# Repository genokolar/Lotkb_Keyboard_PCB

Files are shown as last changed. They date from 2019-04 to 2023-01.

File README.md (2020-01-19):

# Lotkb_Keyboard_PCB
A bluetooth keyboard powered by Lotkb, PCB by Kicad, Schematic fork of https://github.com/Lotlab/BLE60-keyboard  
一个采用Kicad设计制作的Lotkb驱动的蓝牙键盘PCB，原理图参考Lotlab的蓝牙键盘进行更改优化。

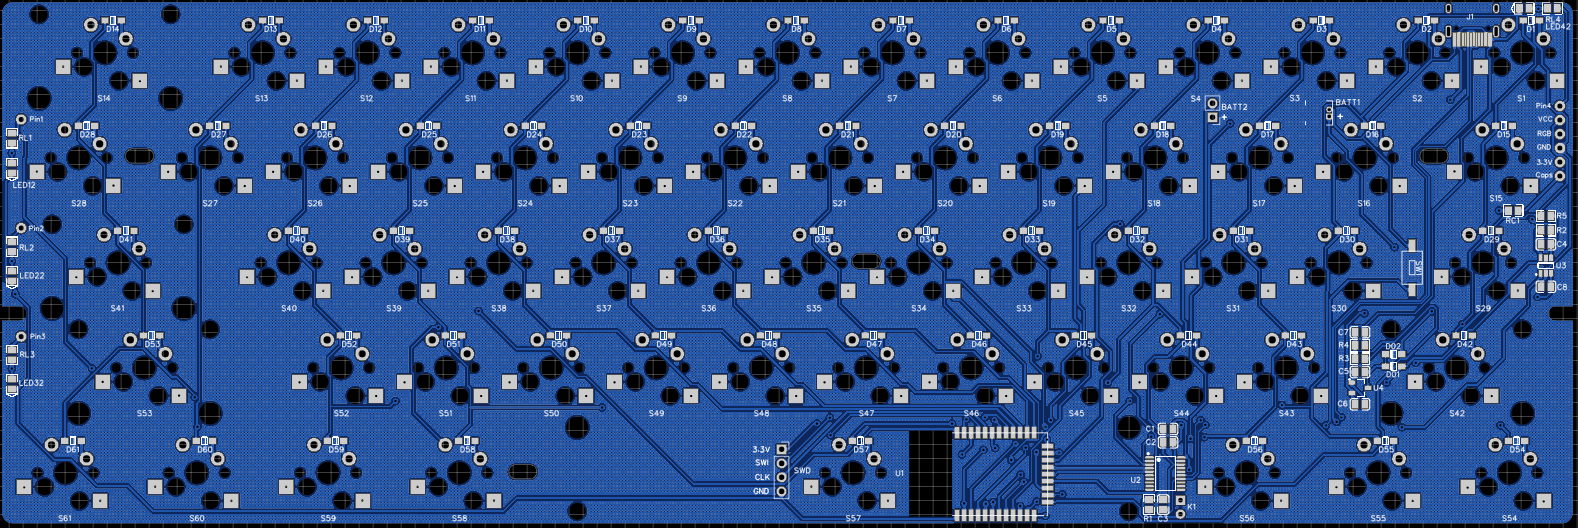
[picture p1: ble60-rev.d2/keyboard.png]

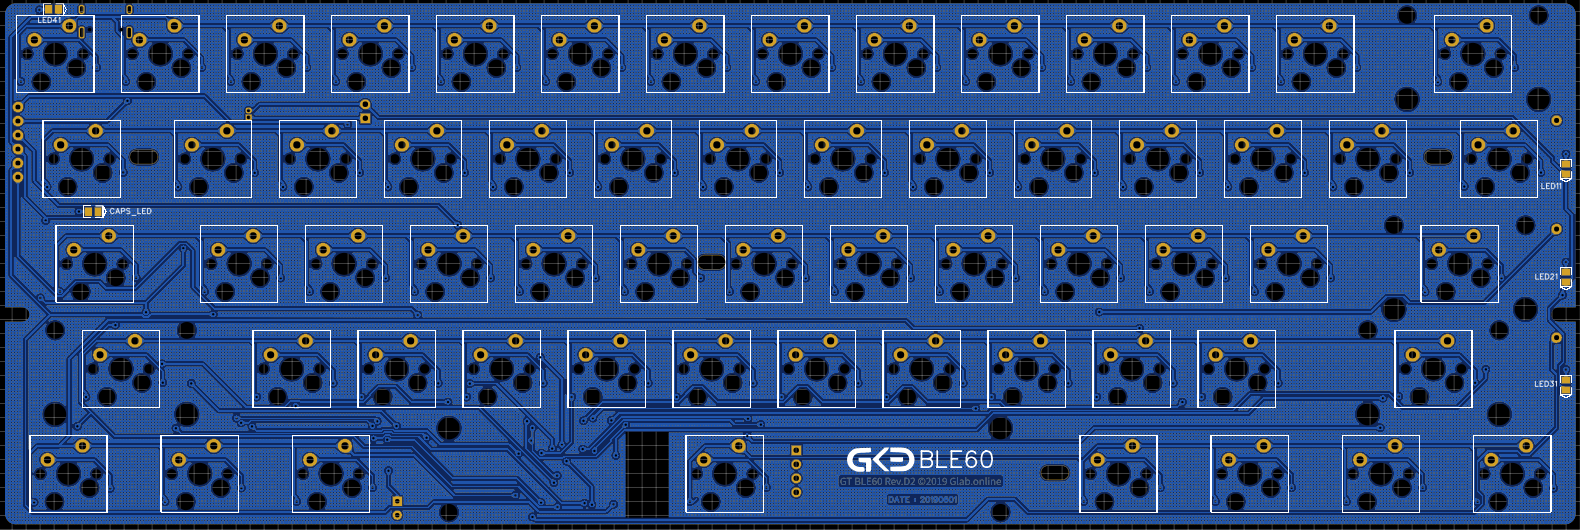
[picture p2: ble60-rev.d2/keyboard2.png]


**生产用Gerber文件可直接用于生产，BOM文件与贴装坐标文件也可直接用于贴装**

using nRF52(or nRF51)  and CH554(or CH552).  
使用 nRF52(或者nRF51) 与 CH554（或者CH552）芯片

Firmware Source Code/固件源码: 
- [nrf51822-keyboard](https://github.com/genokolar/nrf51822-keyboard/tree/GT-BLE60)
- [nrf52-keyboard](https://github.com/genokolar/nrf52-keyboard)

More description/详细信息在此查看：[https://glab.online/](https://glab.online/)

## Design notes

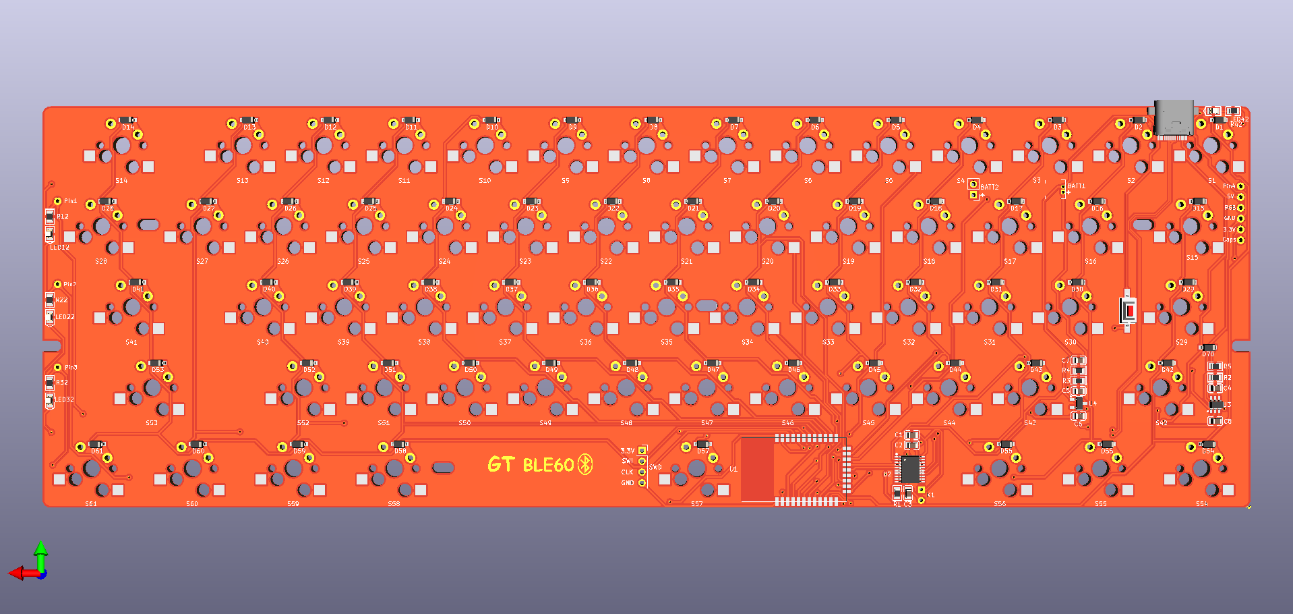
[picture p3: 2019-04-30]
ble60-rev.d/keyboard2.png

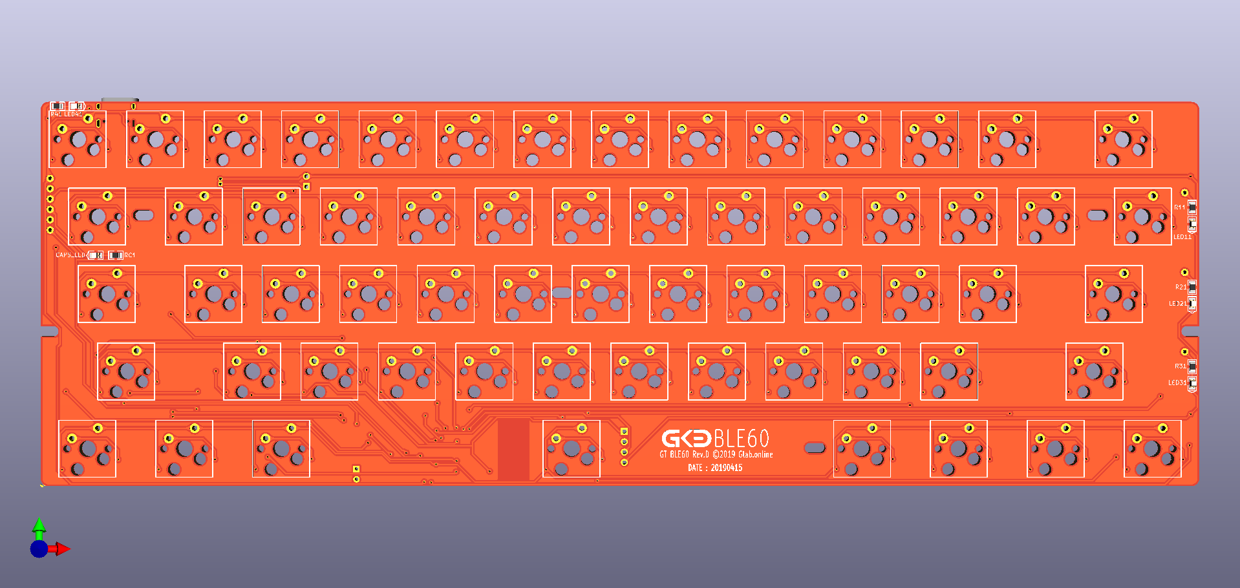
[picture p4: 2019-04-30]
ble60-rev.d/keyboard.png

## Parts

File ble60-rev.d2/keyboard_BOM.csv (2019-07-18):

Comment | Description | Designator | Footprint | LibRef | Pins | Quantity | PartNumber | url
0.1uF | 贴片电容 | C1,C2, | JLC_0805C | libref | 2 | 2
NC/47pF | 贴片电容 | C3, | JLC_0805C | libref | 2 | 1
1uF | 贴片电容 | C4,C5,C6, | JLC_0805C | libref | 2 | 3
10nF | 贴片电容 | C7, | JLC_0805C | libref | 2 | 1
10uF | 贴片电容 | C8, | JLC_0805C | libref | 2 | 1
B5819W SL | 肖特基二极管 | D01,D02, | JLC_SOD-123 | libref | 2 | 2 |  | http://www.vishay.com/docs/88525/1n5817.pdf
1N4148W | 开关二极管 | D1,D2,D3,D4,D5,D6,D7,D8,D9,D10,D11,D12,D13,D14,D15,D16,D17,D18,D19,D20,D21,D22,D23,D24,D25,D26,D27,D28,D29,D30,D31,D32,D33,D34,D35,D36,D37,D38,D39,D40,D41,D42,D43,D44,D45,D46,D47,D48,D49,D50,D51,D52,D53,D54,D55,D56,D57,D58,D59,D60,D61, | JLC_SOD-123 | libref | 2 | 61 |  | https://atta.szlcsc.com/upload/public/pdf/source/20161024/1477288446905.pdf
White LED | 0805 LED | CAPS_LED1, | JLC_0805_LED | libref | 2 | 1
Red LED | 0805 LED | LED11, | JLC_0805_LED | libref | 2 | 1
Red LED | 0805 LED | LED12, | JLC_0805_LED | libref | 2 | 1
Blue LED | 0805 LED | LED21, | JLC_0805_LED | libref | 2 | 1
Blue LED | 0805 LED | LED22, | JLC_0805_LED | libref | 2 | 1
Green LED | 0805 LED | LED31, | JLC_0805_LED | libref | 2 | 1
Green LED | 0805 LED | LED32, | JLC_0805_LED | libref | 2 | 1
Orange LED | 0805 LED | LED41, | JLC_0805_LED | libref | 2 | 1
Orange LED | 0805 LED | LED42, | JLC_0805_LED | libref | 2 | 1
10K | 贴片电阻 | R1, | JLC_0805R | libref | 2 | 1
4.7K | 贴片电阻 | R2, | JLC_0805R | libref | 2 | 1
10M | 贴片电阻 | R3, | JLC_0805R | libref | 2 | 1
2.2M | 贴片电阻 | R4, | JLC_0805R | libref | 2 | 1
1R | 贴片电阻 | R5, | JLC_0805R | libref | 2 | 1
330R | 贴片电阻 | RL3,RL2,RL1,RC1,RL4, | JLC_0805R | libref | 2 | 5
TP4057 | 锂电池充电芯片 | U3, | JLC_SOT-23-6 | libref | 6 | 1 |  | https://atta.szlcsc.com/upload/public/pdf/source/20140228/1457706997013.pdf
XC6206P332MR | 低压差线性稳压 | U4, | JLC_SOT-23-3L | libref | 3 | 1 |  | https://atta.szlcsc.com/upload/public/pdf/source/20130801/1457706628791.pdf
不贴装元件
RF-BM-ND04 | 蓝牙主控板 | U1, | RF-BM-ND01 | LibRef | 33 | 1 |  | https://item.taobao.com/item.htm?spm=a1z09.2.0.0.24672e8d1aBt7Y&id=563254559292&_u=imp3j1b519
CH552T | USB芯片 | U2, | JLC_TSSOP-20 | LibRef | 20 | 1 |  | https://item.taobao.com/item.htm?spm=a1z10.3-c-s.w4002-21223910208.9.55dc6a4bV8yMGt&id=574979089030
Bootloader Button | Bootloader按钮 | SW1, | Switch | LibRef | 2 | 1 |  | https://item.taobao.com/item.htm?spm=a1z09.2.0.0.403d2e8dNmbyeE&id=556985020016&_u=4mp3j15e56
MX1A | MX轴体or凯华轴座 | S6,S28,S2,S4,S5,S7,S8,S9,S10,S11,S12,S13,S14,S15,S16,S17,S18,S19,S20,S21,S22,S23,S24,S25,S26,S27,S29,S30,S31,S32,S33,S34,S35,S36,S37,S38,S39,S40,S41,S42,S43,S44,S45,S46,S47,S48,S49,S50,S51,S52,S53,S54,S55,S56,S57,S58,S59,S60,S61,S1,S3, | Kailh_socket_optional | LibRef | 9 | 61
1.25mm | 1.25mm2P弯针电池接口母座 | BATT1, | PinHeader_2x1.25mm | LibRef | 2 | 1 |  | https://item.taobao.com/item.htm?spm=a1z0d.6639537.1997196601.58.47cf7484bbDVc8&id=528795201308
2.54mm | 2.54mm2P电池接口 | BATT2, | PinHeader_1x02_P2.54mm_Vertical | LibRef | 2 | 1
USB_TYPE_C | 贴片USB-3.1插座 16P | J1, | type-c | LibRef | 18 | 1 |  | https://item.taobao.com/item.htm?spm=a1z0d.6639537.1997196601.76.47cf7484bbDVc8&id=573090887123

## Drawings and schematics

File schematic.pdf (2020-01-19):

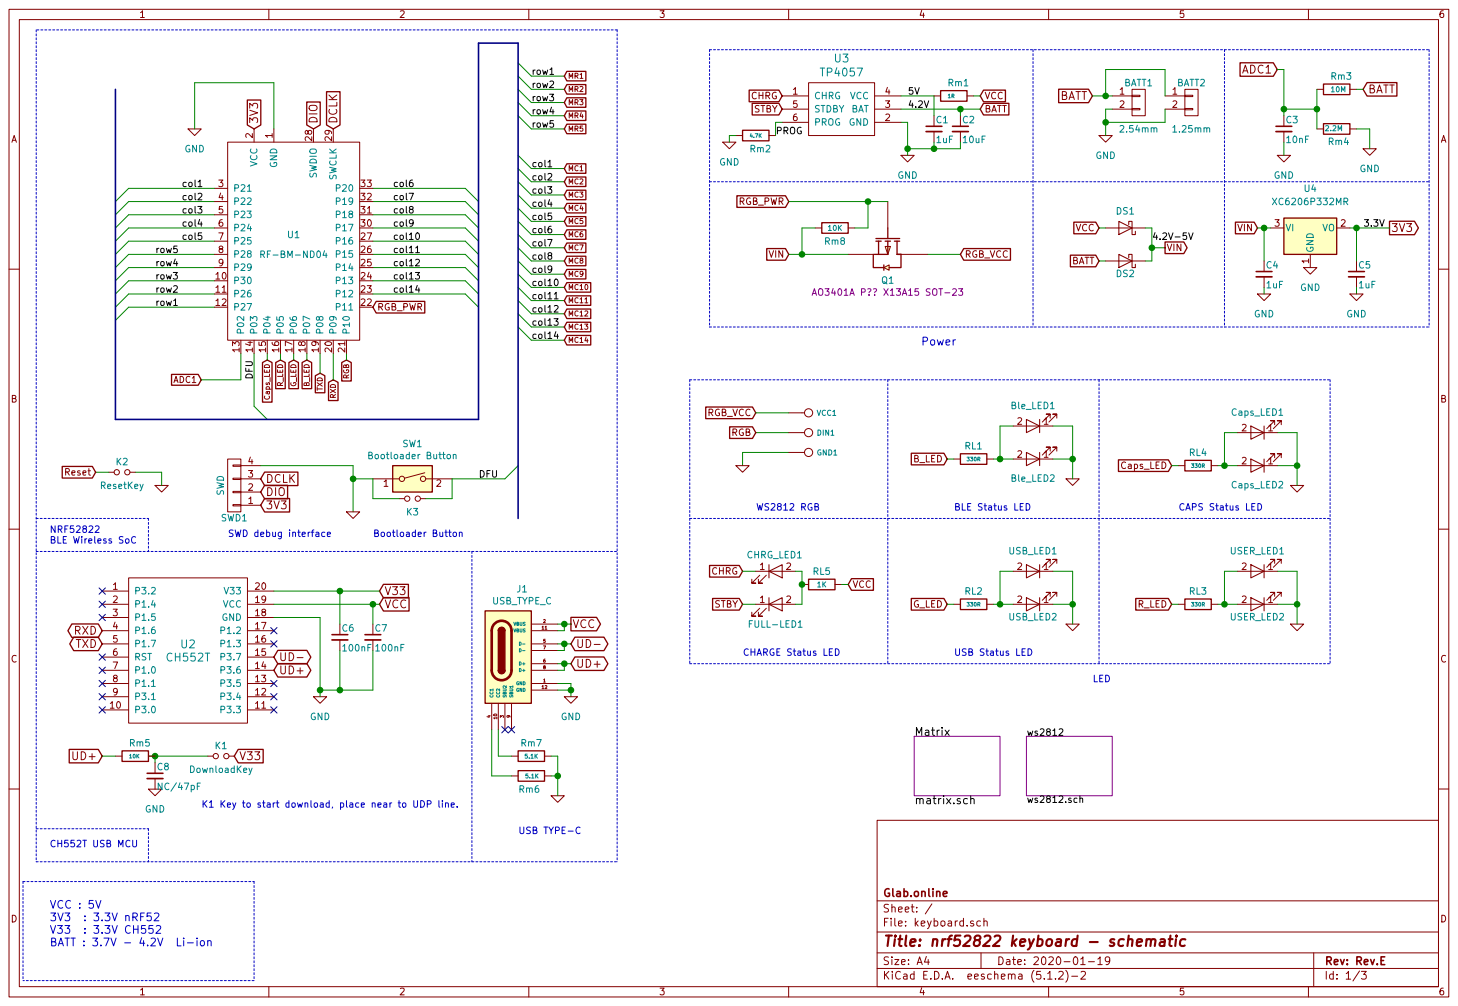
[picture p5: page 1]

2 P09 20 P10 21 P11 22 P12 23 P13 24 P14 25 P15 26 P16 27 SWDIO 28 SWCLK 29 P21 3 P17 30 P18 31 P19 32 P20 33 P22 4 P23 5 P24 6 P25 7 P28 8 P29 9 U1 RF-BM-ND04 CHRG

GND UD+ UD- RXD
TXD

File: keyboard.sch Sheet: / Glab.online

Id: 1/3 Title: nrf52822 keyboard - schematic

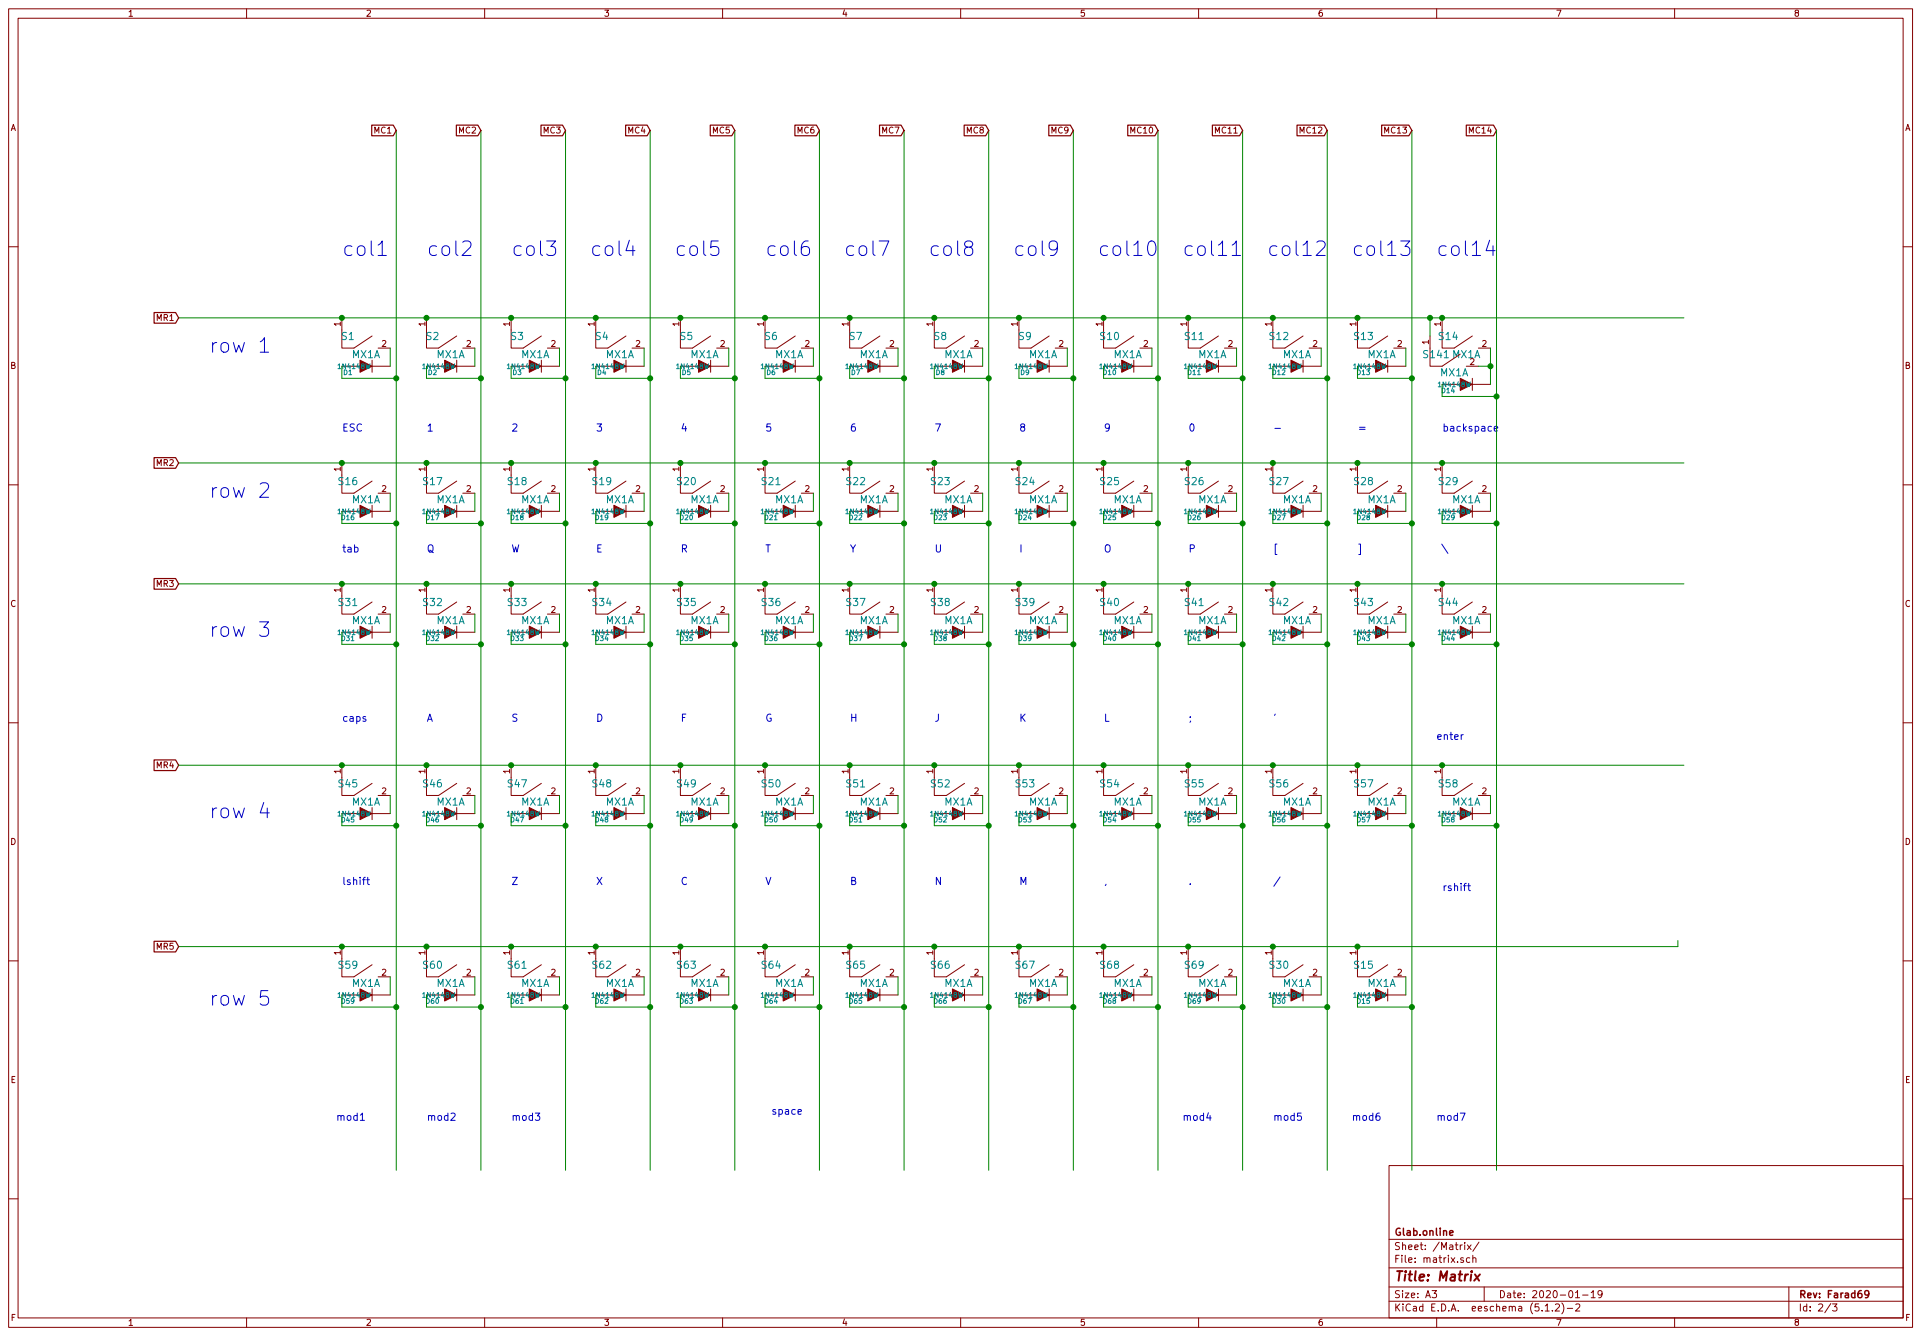
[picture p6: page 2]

File: matrix.sch Sheet: /Matrix/ Glab.online

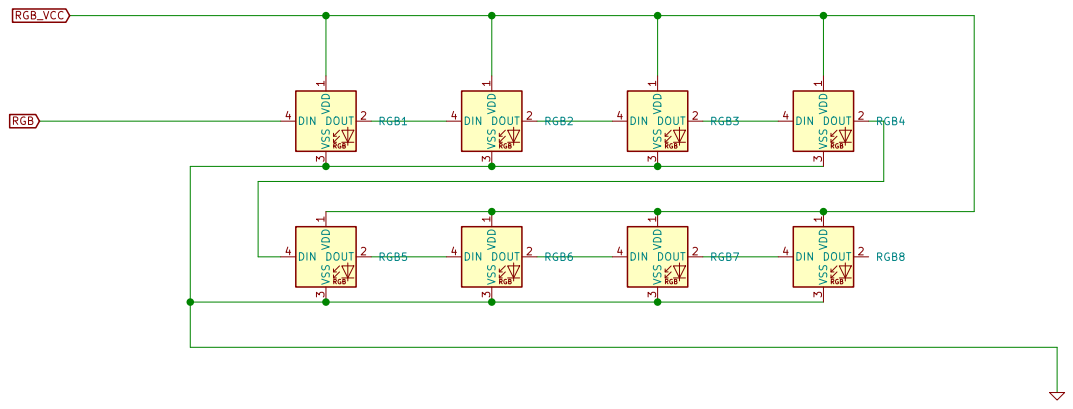
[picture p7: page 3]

File: ws2812.sch Sheet: /ws2812/ Glab.online

Id: 3/3 Title: nrf52822 keyboard - schematic

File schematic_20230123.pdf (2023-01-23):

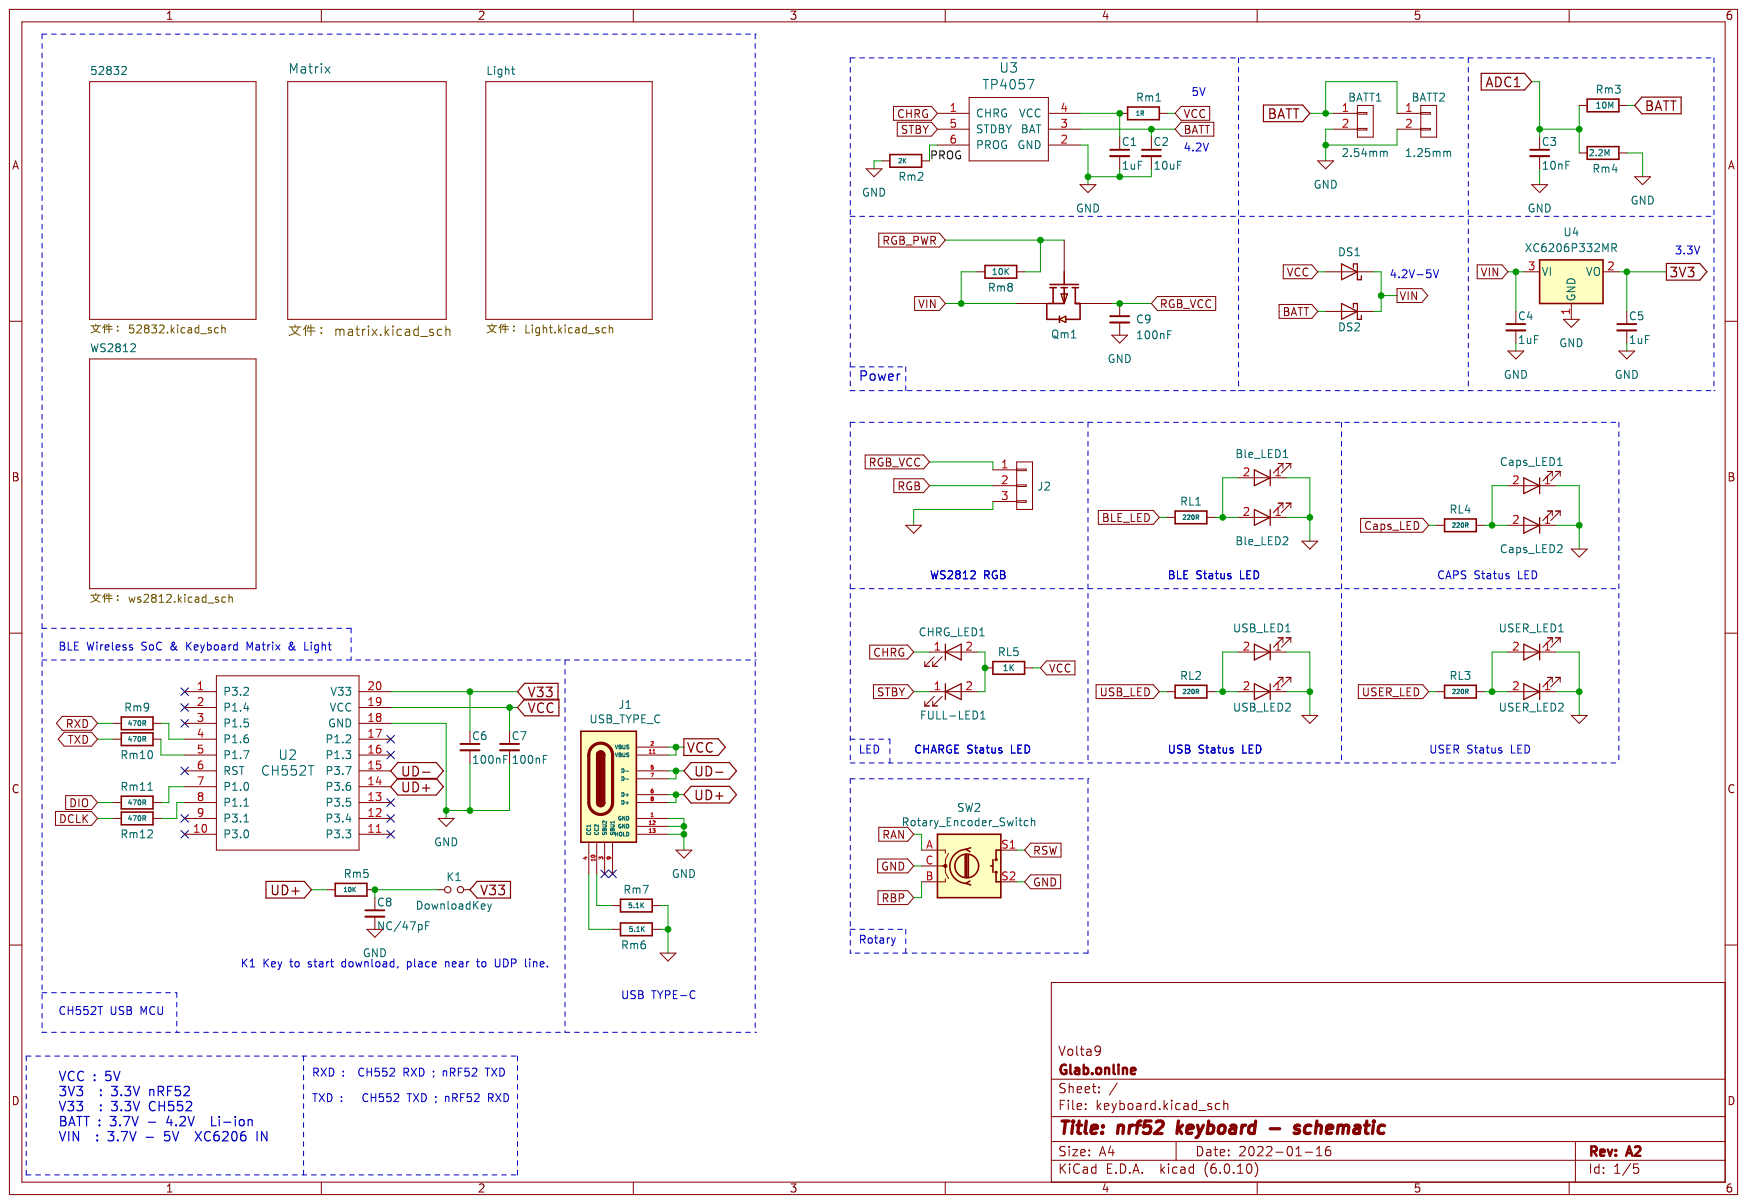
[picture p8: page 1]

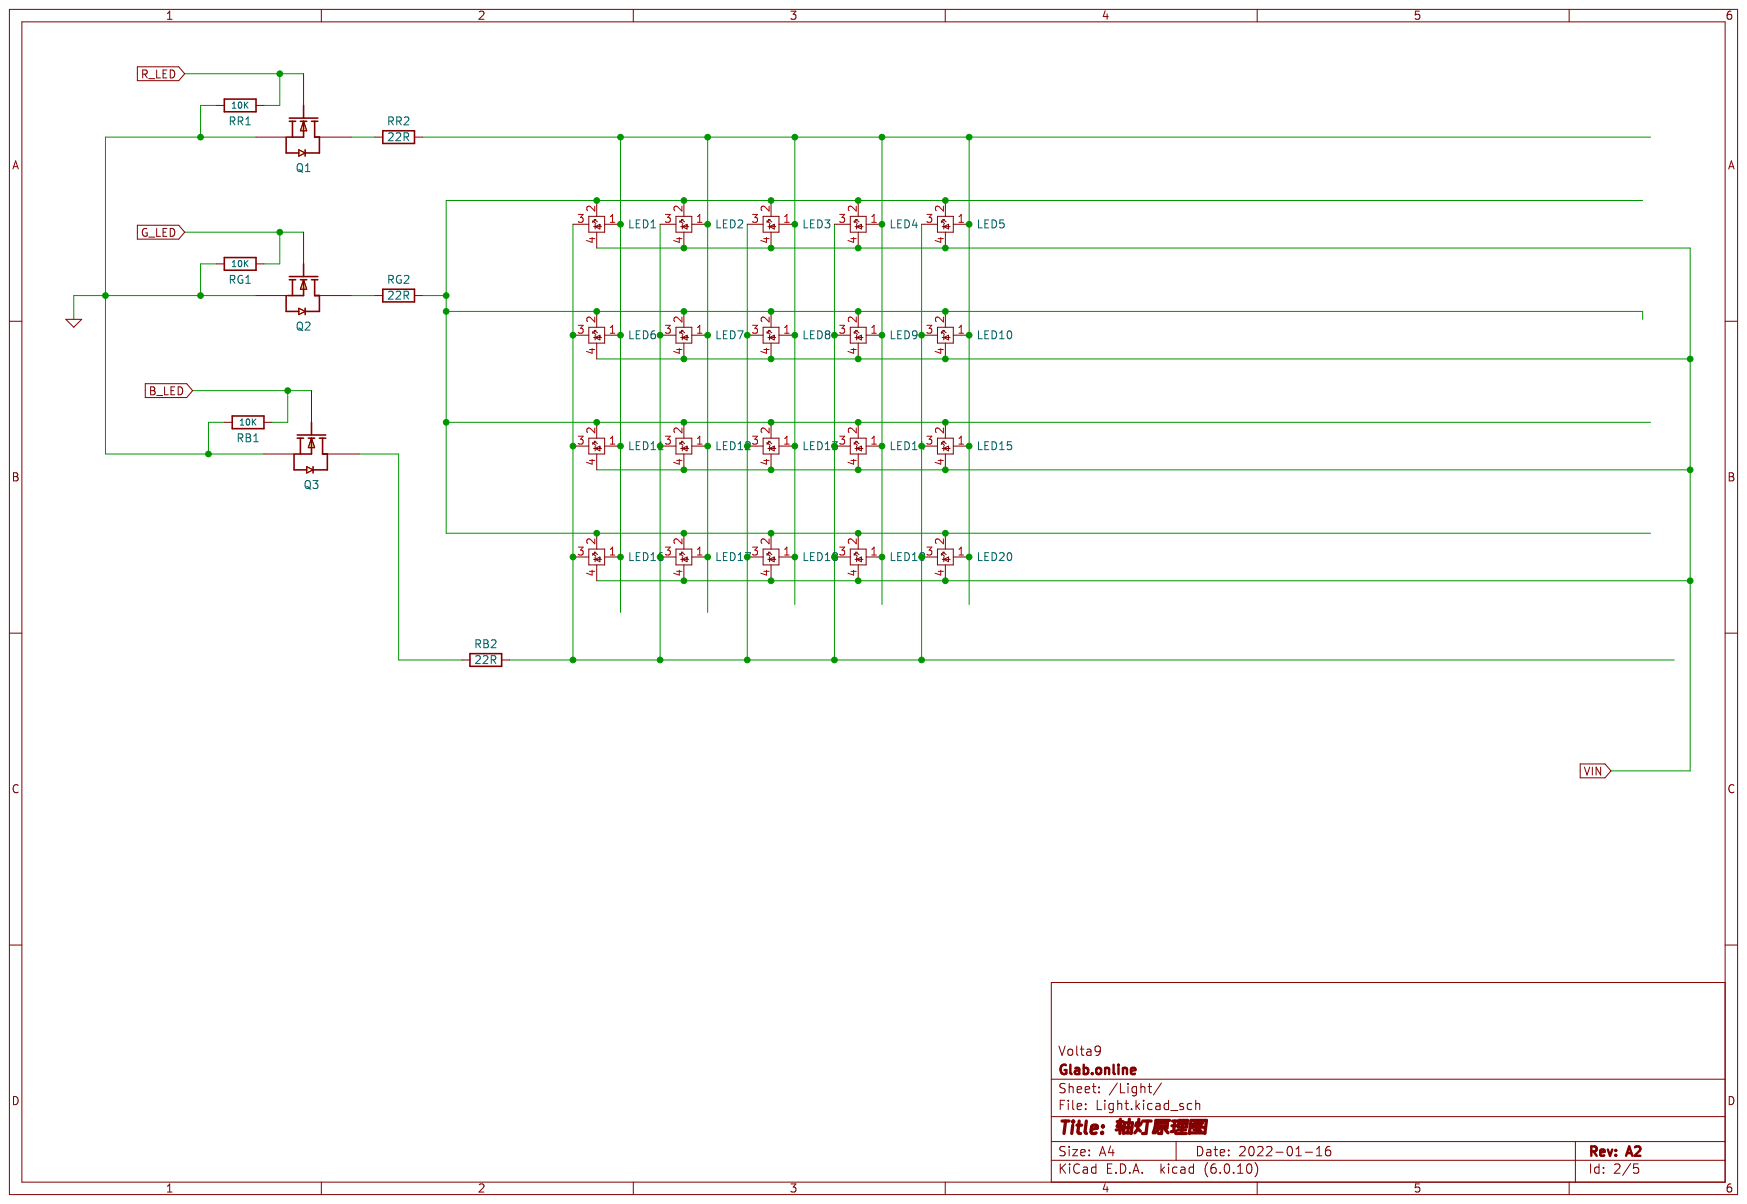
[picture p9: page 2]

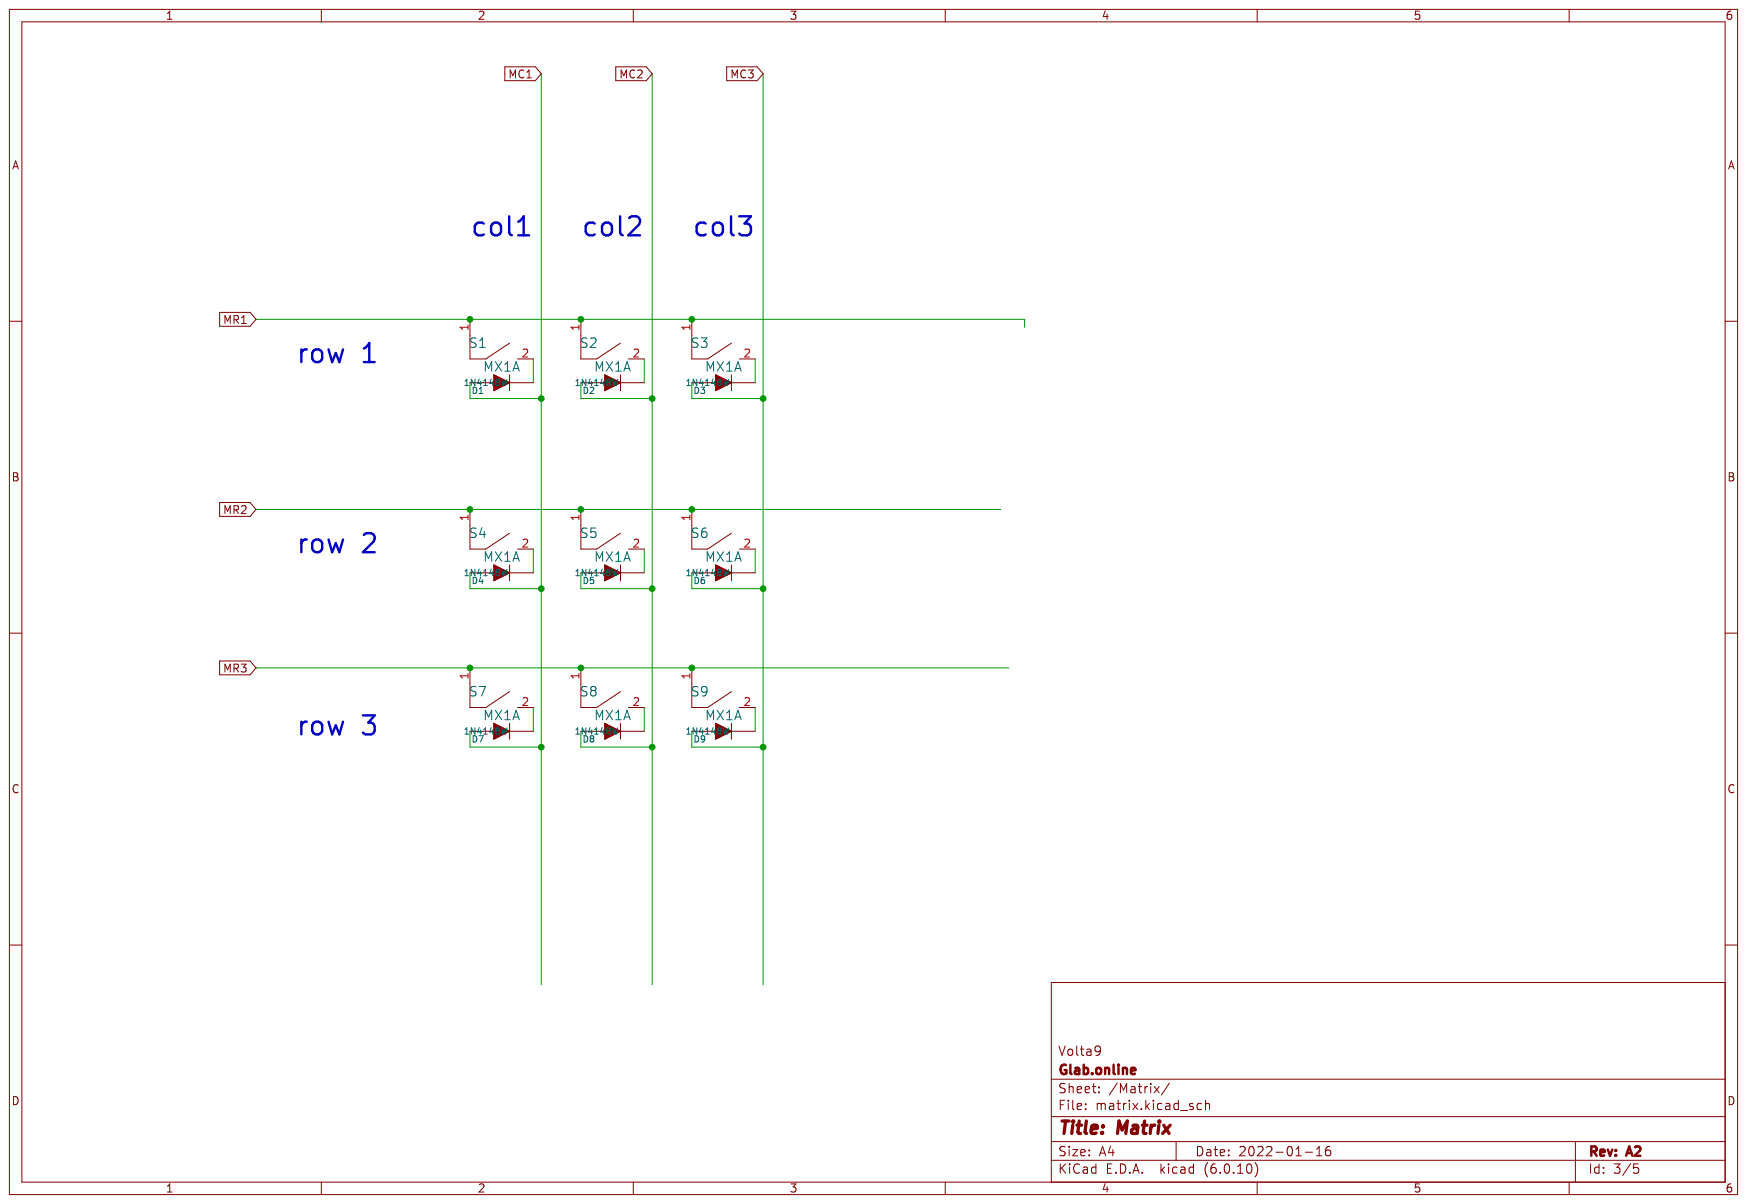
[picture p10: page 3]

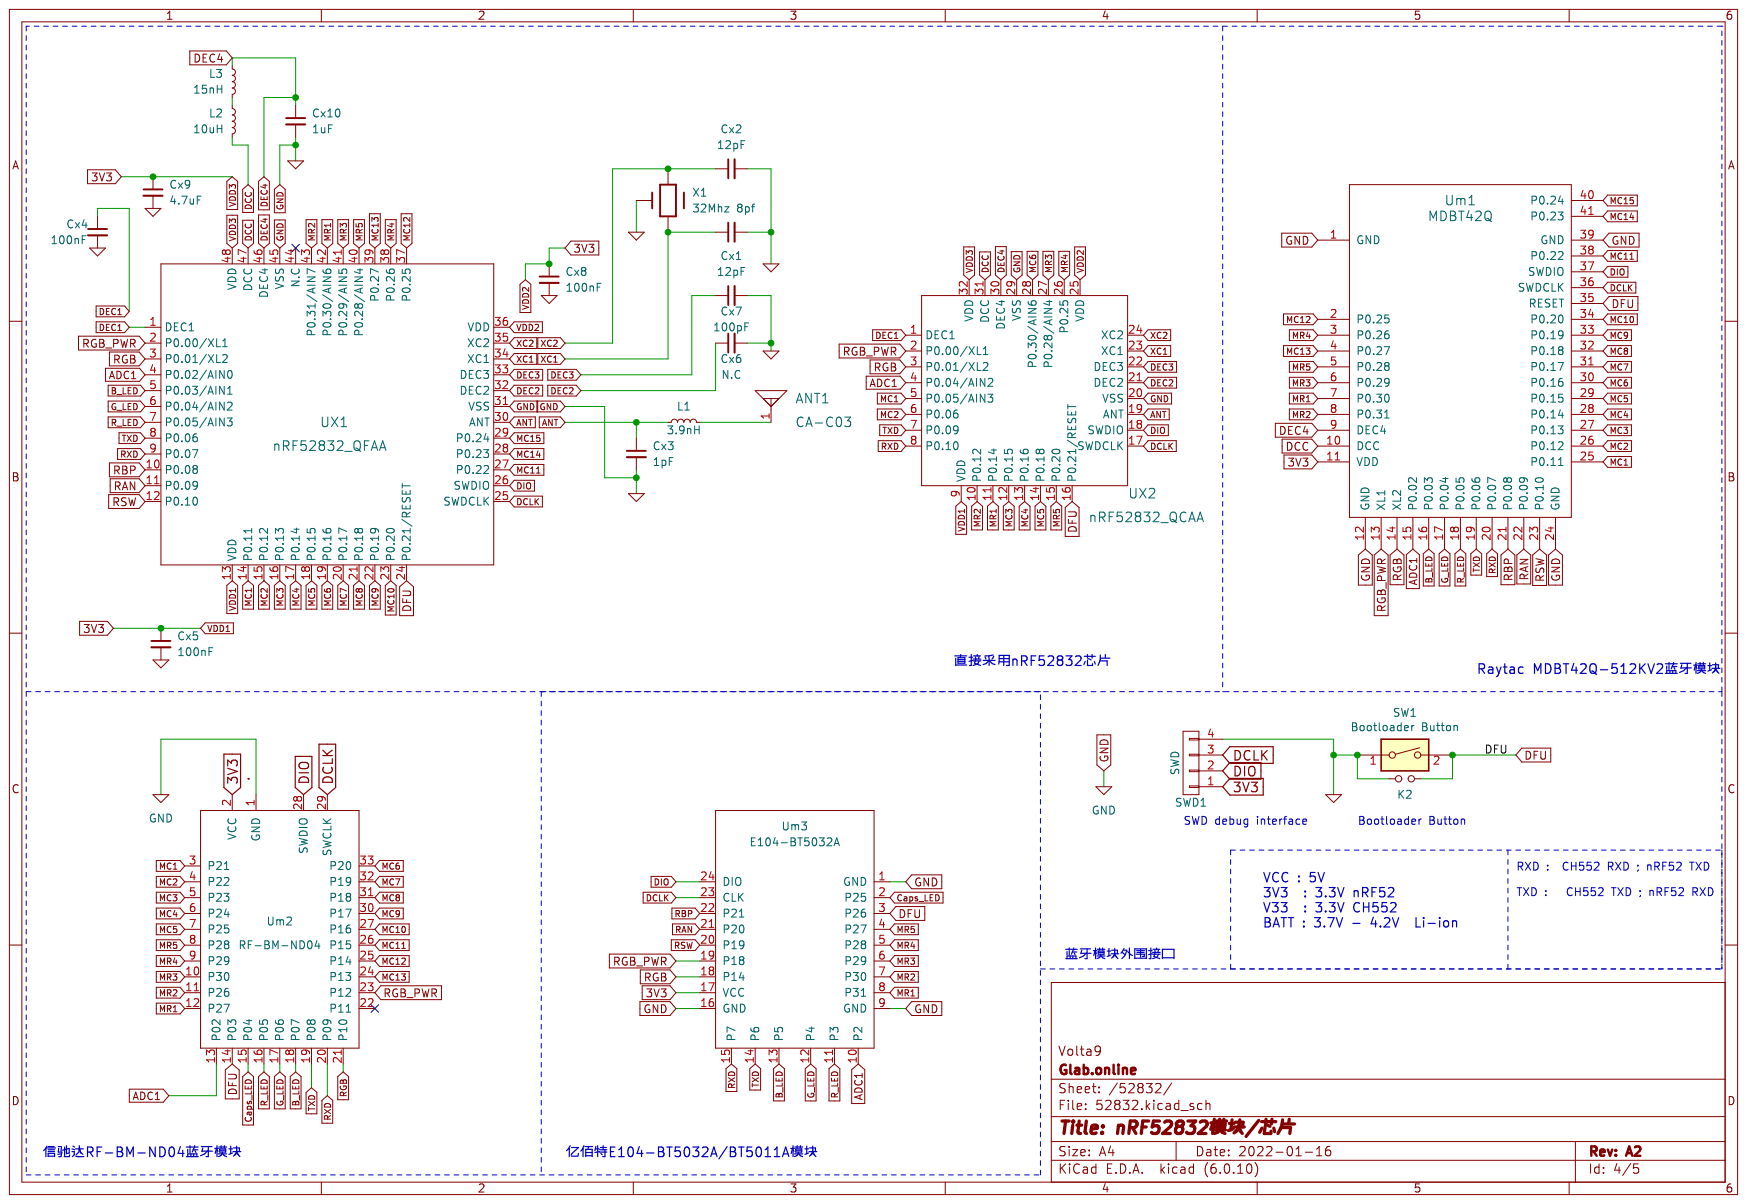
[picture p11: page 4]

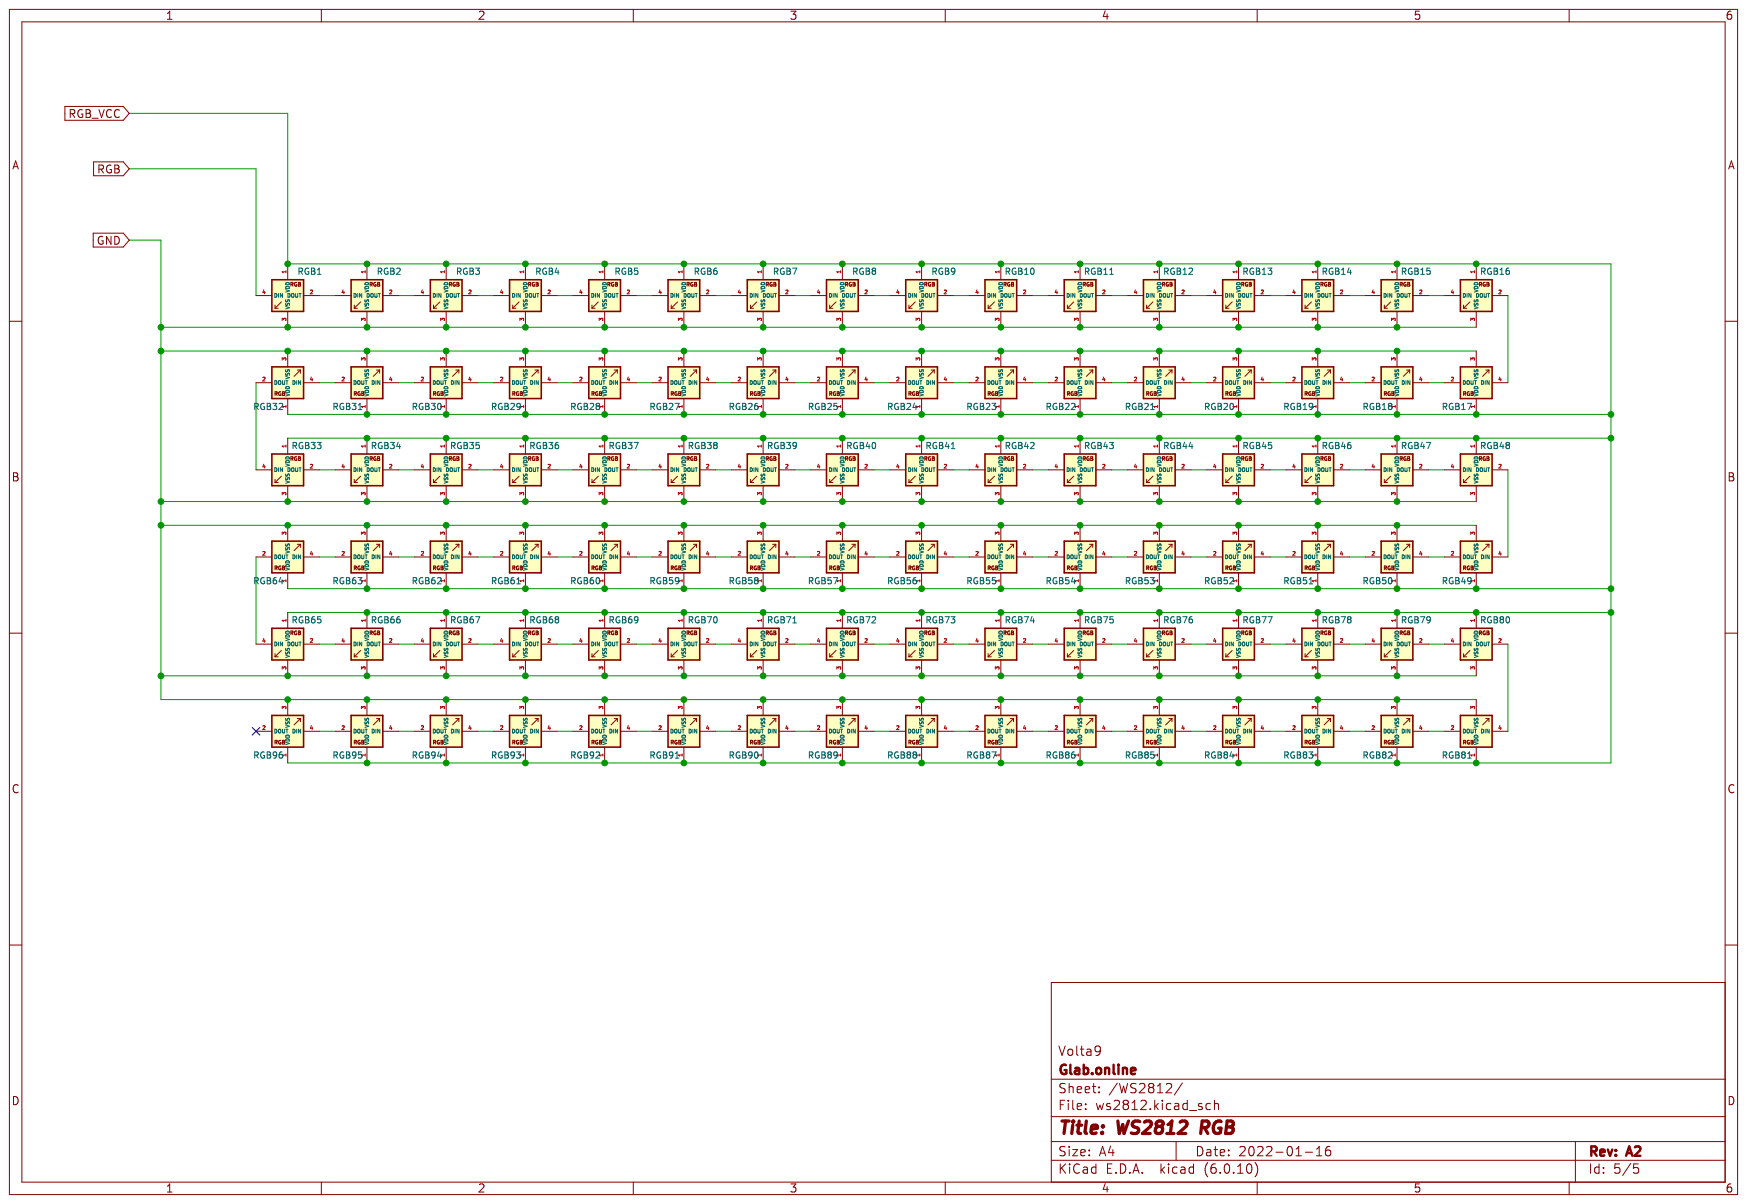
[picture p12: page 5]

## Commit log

2019-04-30 add rev.d
    [keyboard-Bottom_Cu.gbr, keyboard-Bottom_Mask.gbr, keyboard-Bottom_Paste.gbr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]
2019-04-30 添加说明文件、更新BOM表
    [keyboard_BOM.csv]
2019-05-04 更新BOM表，添加不贴装元件
    [keyboard_BOM.csv]
2019-05-04 添加图片
2019-05-04 更正错误
    [keyboard_BOM.csv]
2019-05-11 添加原理图
2019-07-18 添加rev.d2的生产文件
    [Gerber_BoardOutline.GKO, Gerber_BottomLayer.GBL, Gerber_BottomPasteMaskLayer.GBP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]
2019-07-18 更新BOM
    [keyboard_BOM.csv]
2020-01-19 更新原理图、readme
    [Gerber_BoardOutline.GKO, Gerber_BottomLayer.GBL, Gerber_BottomPasteMaskLayer.GBP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]
2020-01-19 Add Omega45 Gerber
2023-01-23 添加新版原理图
